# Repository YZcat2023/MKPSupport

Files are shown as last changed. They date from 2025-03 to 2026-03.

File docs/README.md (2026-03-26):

<div align="center" style="margin: 30px 0 30px 0">
   <a href="https://github.com/YZcat2023/MKPSupport">
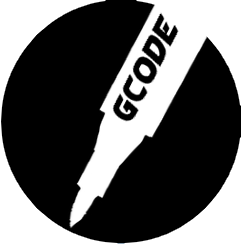
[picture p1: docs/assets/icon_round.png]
icon
      
   </a>
   <h3>MKP Support</h3>

   <p>
      
      
      
      
      
   </p>
   <p>
      </a>
   </p>
</div>

## ✨ What is MKP Support?

Still troubled by hard-to-remove 3D printing supports and the marks they leave behind? MKP Support makes removing supports as easy as peeling off a sticky note!

**In simple terms**: We've invented a method of applying an adhesive layer on the support interface, which leaves the contact surface smooth and flat, almost invisible, and incredibly easy to remove.

## 🖊️ Why is it better than traditional methods?

**Compared to standard supports**: No more prying with knives or pulling with pliers. Say goodbye to scratched fingers, while achieving an exceptionally smooth finish.

**Compared to water-soluble supports**: No need to buy specialized water-soluble filaments, no worries about moisture absorption. The results are nearly identical, but the cost is completely different.

**Extremely simple assembly**: The parts only require magnets, screws, springs (for P1/X1), pen refills, etc.

## 🎯 Expected Results

✅ **Saves Time**: Support removal goes from minutes to seconds.

✅ **Saves Material**: MKP doesn't require material changes or flushing.

✅ **Perfect Surface**: The support surface is flat and smooth.

✅ **Increases Success Rate**: Reduces the risk of damage during support removal.

## 📸 Demo

Showcase of actual printed test pieces. Note the extremely smooth support surface:

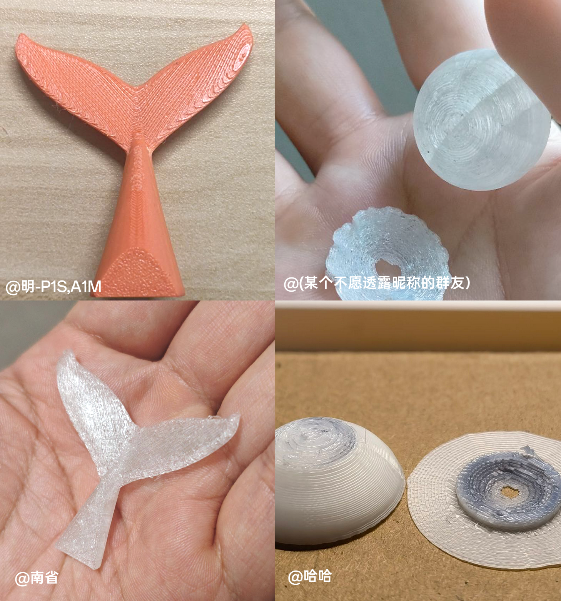
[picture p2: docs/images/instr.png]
sample


## 📦 Quick Start

### 1. Prepare Materials

🛒 You need to purchase the components indicated in the BOM list for your specific printer model.

  <a href="Printers/P1/"><strong>P1</strong></a><br>
  <a href="Printers/A1/"><strong>A1</strong></a><br>
  <a href="Printers/A1M/"><strong>A1M</strong></a>
### 2. Install Hardware

- **Download and Print** the parts for your printer model.
- **Assemble the parts**: Follow the instructional video to assemble the device.

### 3. Configure Software

**Download the program**: [Go to the Releases page](https://github.com/YZcat2023/MKPSupport/releases)

## 🛠️ In Development

🔧 **Planned for the near future**:

- [x] Multi-color printing support
- [x] More fine-tuning options
- [ ] Support for more printer models

📋 **See the full list**: [Issues page](https://github.com/YZcat2023/MKPSupport/issues)

For a complete list of proposed features (and known issues), please refer to the [issues](https://github.com/YZcat2023/MKPSupport/issues).

## 🤝 Contributing to This Project

- We are looking for capable developers to join us and make this project better. If you are willing to join, please feel free to contact us. We welcome you warmly.
- You can also help the developers by submitting [Pull Requests](https://github.com/YZcat2023/MKPSupport/pulls)! Submitting a pull request is also a way to contribute to this project. We will review your submission and then take over maintenance.
- Also, please see the [issues](https://github.com/YZcat2023/MKPSupport/issues).

### 🙏 Contributors

- Thanks to thyfk for programming supports and okookey for translating the English instructions

<!-- TODO: Contributor List -->

## 📄 License

This project is licensed under **The Unlicense**. This means you are free to use, modify, and distribute the code in this project. For more information, please refer to [`LICENSE`](../LICENSE).

## 📞 Contact Us

Please send an email to `Jhmodel01@outlook.com` or join the QQ group: 668350689.

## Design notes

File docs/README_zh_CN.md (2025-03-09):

<div align="center" style="margin: 30px 0 30px 0">
   <a href="https://github.com/YZcat2023/MKPSupport">
      icon
   </a>
   <h3>MKP Support</h3>
   <p>更好的 FDM 打印打印支撑方案</p>
   <a href="README.md">English</a> |
   <a href="#"><b>中文(简体)</b></a>
   <p>
      
      
      
      
   </p>
   <p>
      <a href="MKP%20Manual.pdf">
         <strong>Download MKP Manual »</strong>
      </a>
   </p>
</div>

## 关于本项目的一些想法

使用 [FDM 3D打印机](https://en.wikipedia.org/wiki/Fused_filament_fabrication#Fused_deposition_modeling) 打印零件时，
支撑总是一个让人头疼的问题。它们有时很难拆除，拆除支撑后的零件表面也不太平整。那么，降低支撑层与零件间的层粘也许是一个好主意？
试试看 [MKP Support](https://github.com/YZcat2023/MKPSupport) 吧，它能实现相当好的效果：

支撑面光滑平整不粘手，且颜色与零件主体没有区别。由于加入了熨烫支撑面的功能，也许效果比使用水溶支撑还要好。只需要四块磁铁，两个螺丝，一瓶液体胶等等，您就可以升级您的打印机。

我找来了一只马克笔涂抹支撑面，结果相当成功。接触面看上去很平滑。
不过，马克笔的方案并不十分令人满意：它似乎不能在 [CoreXY](https://en.wikipedia.org/wiki/CoreXY) 机器上工作。
于是我找来了一些*gluepen refills*(**点点胶替芯** in Chinese）。
胶水是透明的，因此接触面效果更加好了。不过，它似乎很容易就用完了。所以我设计了一个零件用来储存胶水，并且重新编写了程序。

### 想要达到的效果

- 减少时间与材料的浪费
- 提高接触面的表面效果
- 提高打印的成功率

## 演示

- 这是一些测试打印件, 可以从图片中看到支撑面打印效果

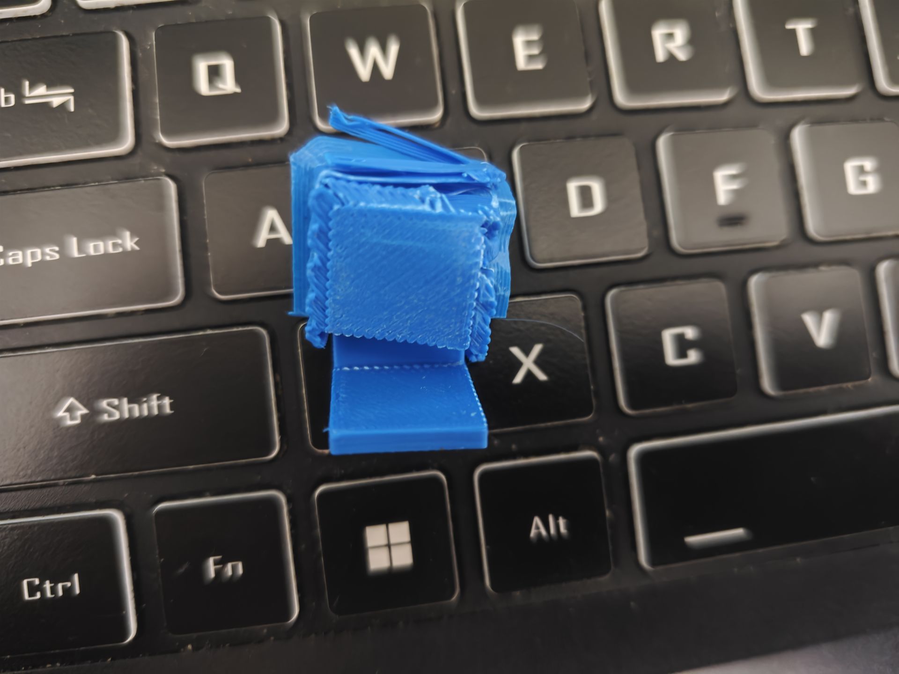
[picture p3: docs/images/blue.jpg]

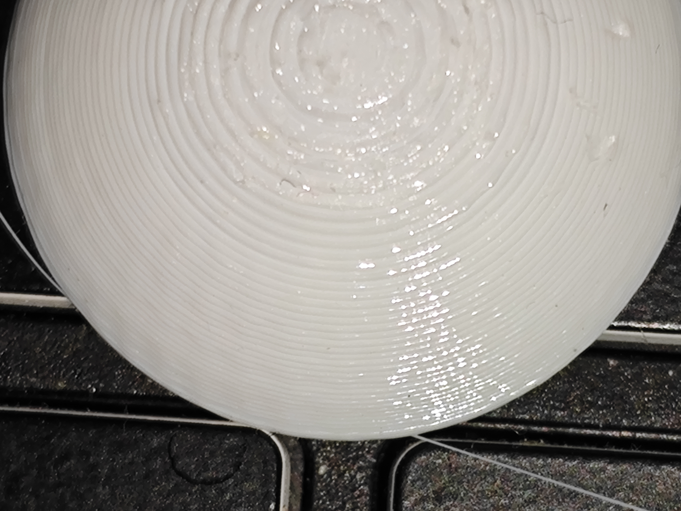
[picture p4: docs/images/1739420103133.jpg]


## 准备工作

想要获取更多信息，请参阅 [MKP Manual.pdf](MKP%20Manual.pdf)

1. 准备材料:
   * 点点胶笔芯、透明液体状办公胶水
   * M2.5*5 螺丝 **x 2**
   * 直径4毫米，厚度1.5毫米的磁铁 **x 4**
2. 模型的打印与装配:
   * 下载我们准备好的3D模型并完成打印。
   * 将打印件组装后安装在3D打印机的合适位置。
   * 根据实际机型可能需要调整模型完成适配。
3. 软件配置
   * 请到 [Releases](https://github.com/YZcat2023/MKPSupport/releases/latest) 页面下载对应的程序。
   * 将下载后的文件放在合适的位置，然后打开程序，在弹出的对话框内填写必要的参数生成配置文件。
   * 复制刚刚下载的程序路径到 Orca Slicer 的后处理脚本中。
     ```gcode
     ; 例如
     "C:/User/name/mkp/mkp.exe"
     ```
   * 调整切片设置确保能够完成 `gcode` 的插入

## 计划列表 & 已知问题

- [ ] 多色打印支持
- [x] 熨烫支持选项

有关提议功能（和已知问题）的完整列表，请参阅 [issues](https://github.com/YZcat2023/MKPSupport/issues)

## 为此项目做出贡献

- 我们正在寻找有能力的开发人员加入我们，让此项目变的更好，如果您愿意加入我们，欢迎联系我们，我们非常欢迎。
- 您也可以帮助开发者提交  [PullRequests](https://github.com/YZcat2023/MKPSupport/pulls)！
  提交请求也是一种对此项目的贡献方式，我们会审阅您的提交，然后接管维护下去。
- 另请参阅 [issues](https://github.com/YZcat2023/MKPSupport/issues)

### 贡献名单

- Thanks to thyfk for programming supports and okookey for translating the English instructions

<!-- TODO: 贡献者成员名单 -->

## License

此项目采用 **The Unlicense** 许可授权。这意味着您可以自由使用、修改、分发本项目中的代码，有关信息请参阅 [`LICENSE`](../LICENSE)

## 联系我们

请发送邮件到 `Jhmodel01@outlook.com`

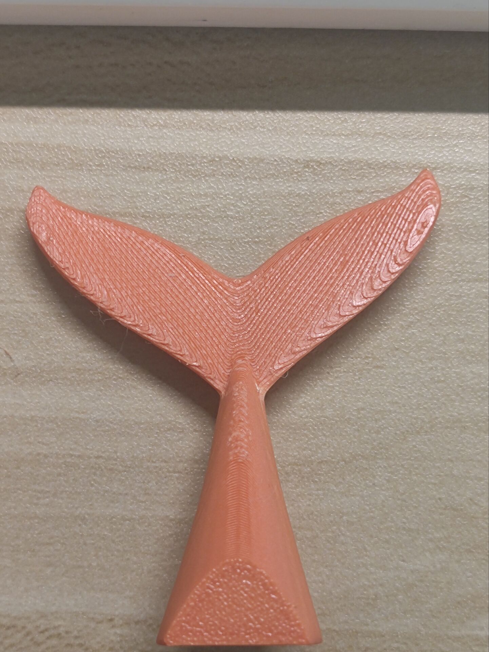
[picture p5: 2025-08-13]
docs/images/whale.jpg

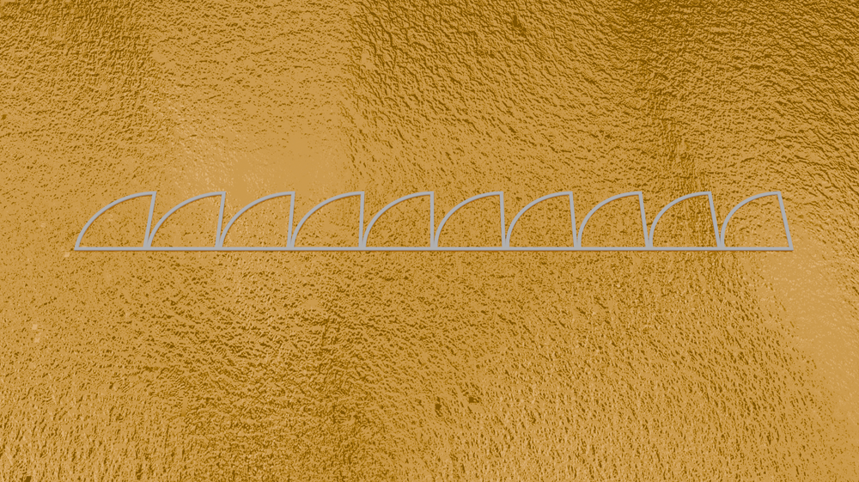
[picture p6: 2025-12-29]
resources/lshape.png

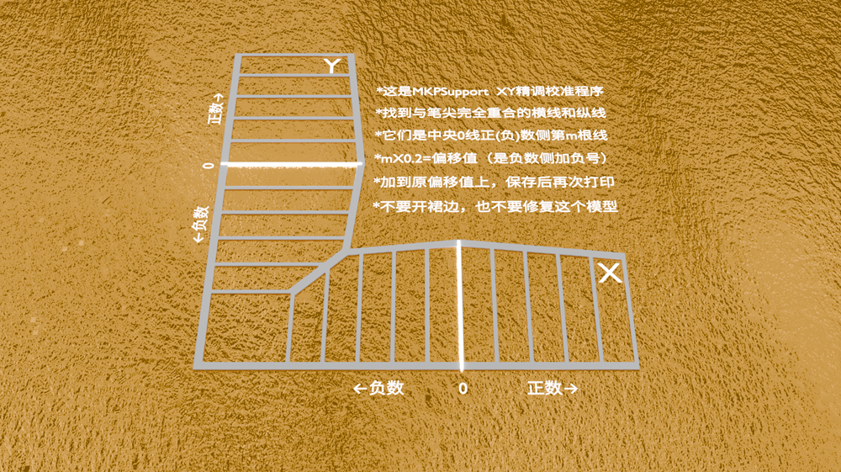
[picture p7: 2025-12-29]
resources/xy_calibr.png

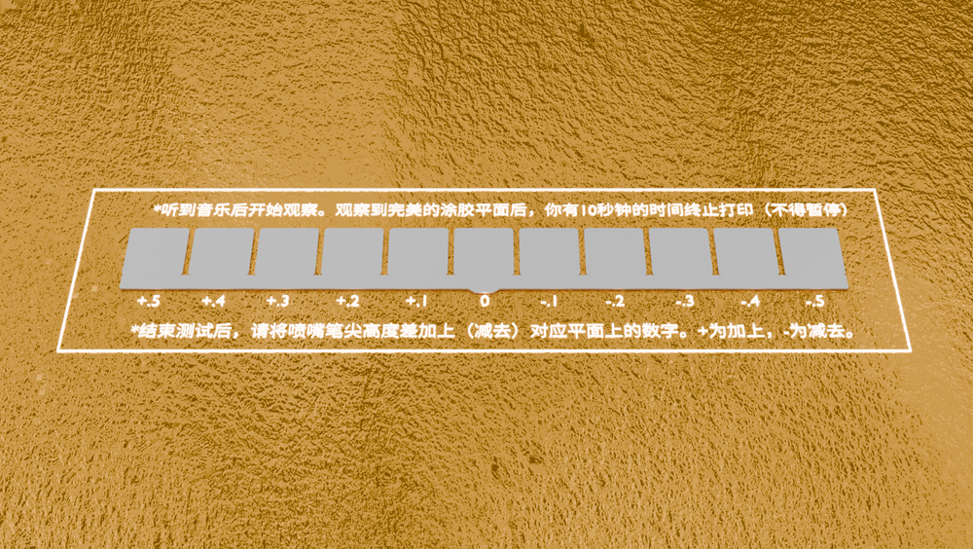
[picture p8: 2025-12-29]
resources/z_calibr.png

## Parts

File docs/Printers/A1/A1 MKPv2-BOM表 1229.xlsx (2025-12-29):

项目 | 所需数量 | 用途 | 淘宝链接 | 备注
大容量高温消失笔芯 | 若干，买替芯就够了 | 笔芯 | 【淘宝】7天无理由退货 https://e.tb.cn/h.7TaKxUg8qL7QzkJ?tk=IIopfzxPCTx HU006 「巨无霸高温消失笔芯大容量服装厂记号笔划线熨烫加热自动褪色无痕」 点击链接直接打开 或者 淘宝搜索直接打开 | 点点胶替芯不再作为推荐
4mm直径2mm厚度N35磁铁 | 至少5 个，以防万一可以多买几个 | 磁吸 | 【淘宝】https://e.tb.cn/h.SyAmDUdPumDhL0F?tk=vin3fLGG5OZ CZ193 「磁铁强力高强小磁钢吸铁石迷你片贴片圆形长方形钕永磁铁方块打捞」 点击链接直接打开 或者 淘宝搜索直接打开 | N52太强了，可能不合适
M2.5*5平头螺丝 | 至少 9 枚 | 组装 | 【淘宝】大促价保 https://e.tb.cn/h.TK1PfH7ZzDrkUwZ?tk=xzIGe6OmARt HU591 「304不锈钢CM超薄头大平头极低扁平C头内六角螺丝钉M2.5M3M4M5M6M8」

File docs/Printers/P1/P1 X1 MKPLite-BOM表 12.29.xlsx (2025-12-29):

项目 | 所需数量 | 用途 | 淘宝链接 | 备注
大容量高温消失笔芯 | 若干，买替芯就够了 | 笔芯 | 【淘宝】7天无理由退货 https://e.tb.cn/h.7TaKxUg8qL7QzkJ?tk=IIopfzxPCTx HU006 「巨无霸高温消失笔芯大容量服装厂记号笔划线熨烫加热自动褪色无痕」 点击链接直接打开 或者 淘宝搜索直接打开 | 点点胶替芯不再作为推荐
4mm直径2mm厚度N52磁铁 | 至少5 个 | 磁吸，嵌入打印的外壳 | 【淘宝】退货运费险 https://e.tb.cn/h.hyI3OSTP9Ipsg0g?tk=OOv04L8GONQ CZ193 「N52强磁小圆形2-8mm迷你强力吸铁石高性能钕铁硼小磁铁超强吸磁钢」 点击链接直接打开 或者 淘宝搜索直接打开
M2*5平头螺丝 | 若干 | 组装 | 【淘宝】大促价保 https://e.tb.cn/h.TK1PfH7ZzDrkUwZ?tk=xzIGe6OmARt HU591 「304不锈钢CM超薄头大平头极低扁平C头内六角螺丝钉M2.5M3M4M5M6M8」
弹簧（0.4*4.5*18mm) | 一根(自用的话不需买） | 回弹 | https://mobile.yangkeduo.com/goods2.html?ps=6SXQYdtmWP | 可从其他圆珠笔拆出

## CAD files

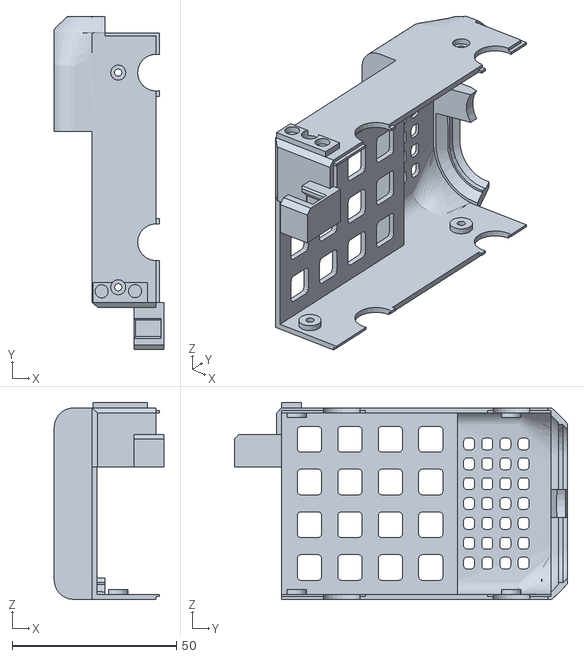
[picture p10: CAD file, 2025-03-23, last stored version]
Printer Parts/Bambu/Bambu P1,X1/后盖.stl
33.4 x 101.4 x 59.9

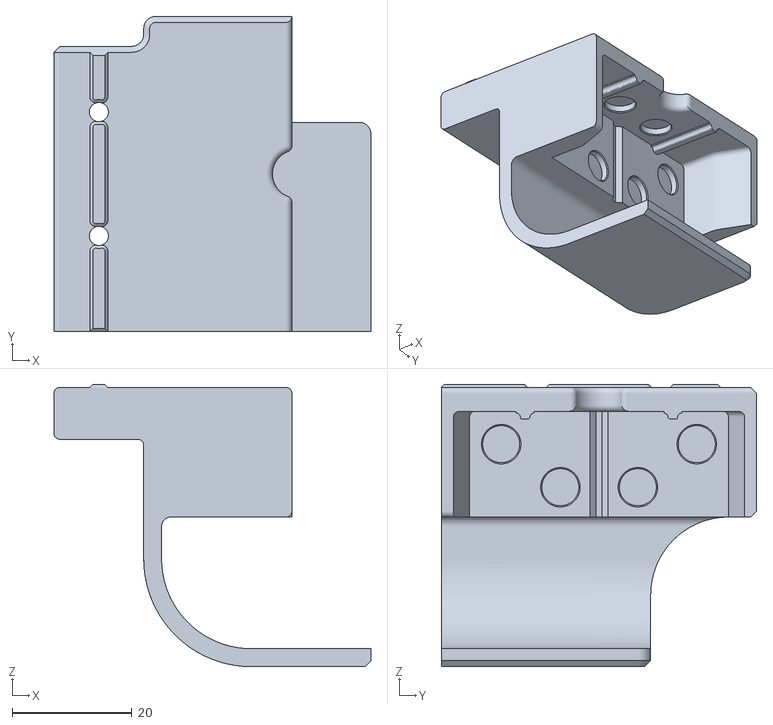
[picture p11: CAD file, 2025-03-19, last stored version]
Printer Parts/Voron/Voron2.4/胶箱停靠站.stl
53.0 x 52.7 x 47.2

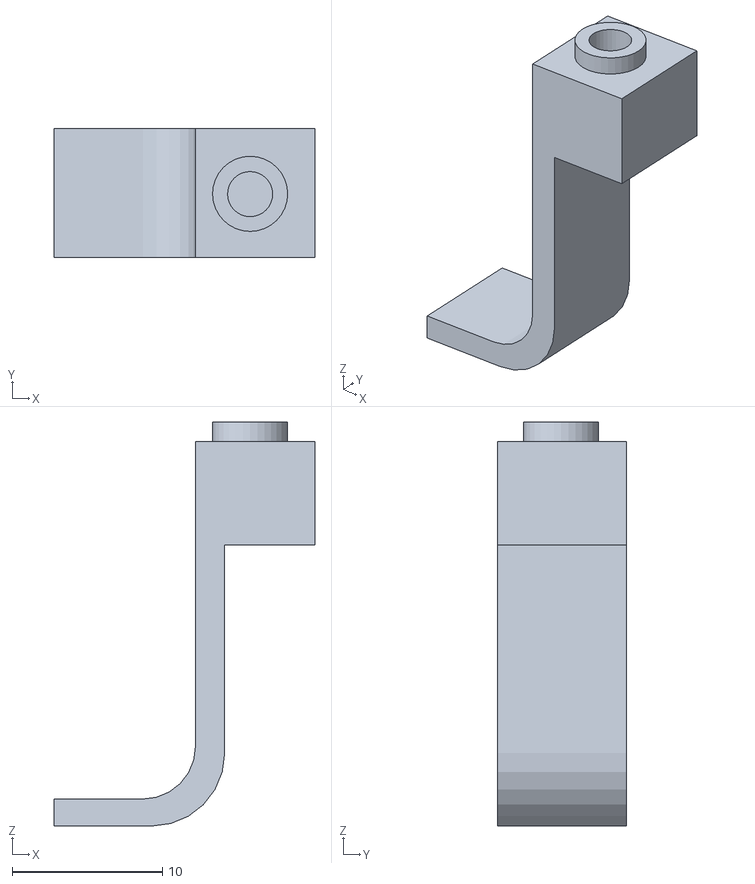
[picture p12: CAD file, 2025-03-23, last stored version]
Printer Parts/Bambu/Bambu P1,X1/笔垫.stl
17.3 x 8.55 x 26.9

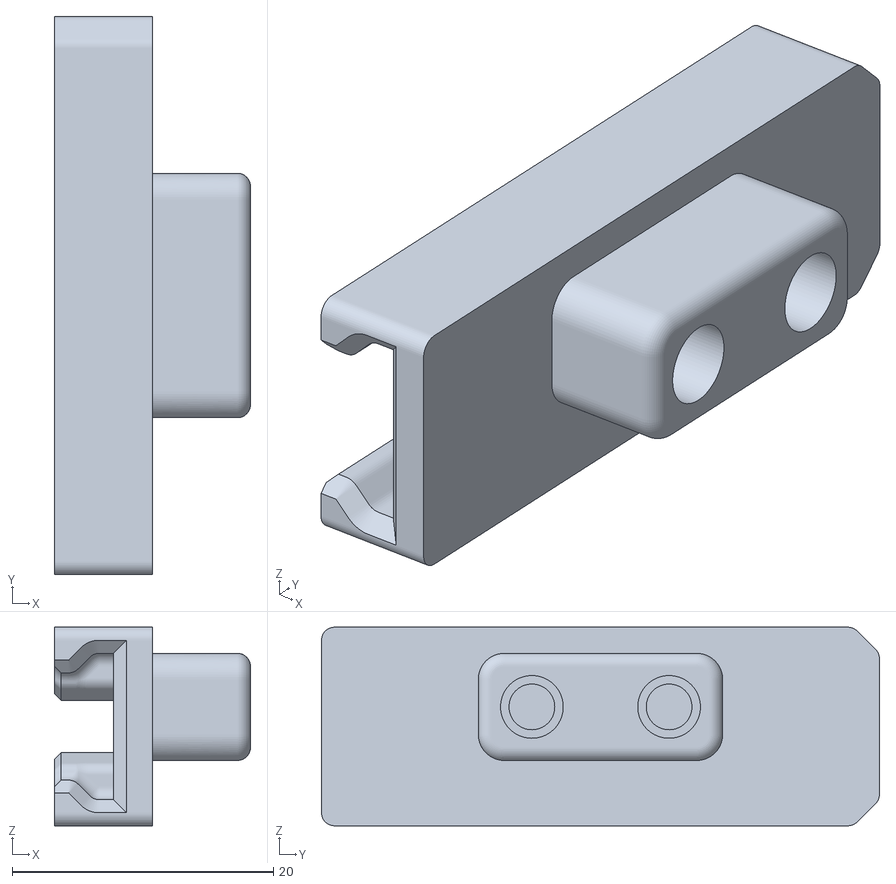
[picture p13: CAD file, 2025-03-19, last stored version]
Printer Parts/Voron/Voron2.4/打印头滑槽.stl
15.0 x 42.7 x 15.2

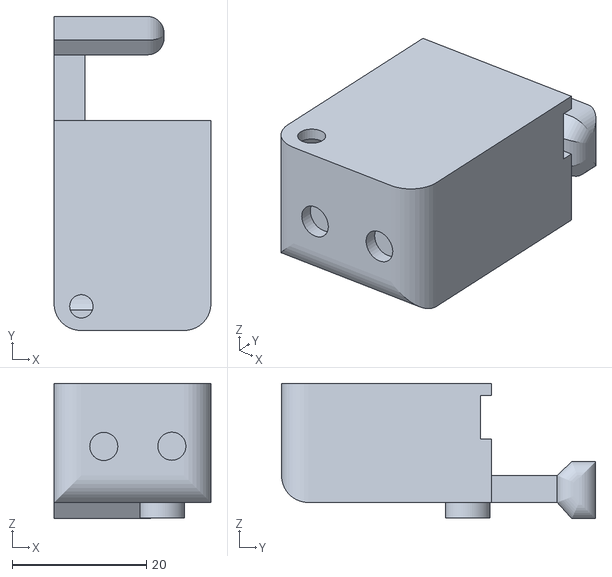
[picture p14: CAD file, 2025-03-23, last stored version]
Printer Parts/Bambu/Bambu P1,X1/胶箱.stl
23.4 x 46.9 x 20.2

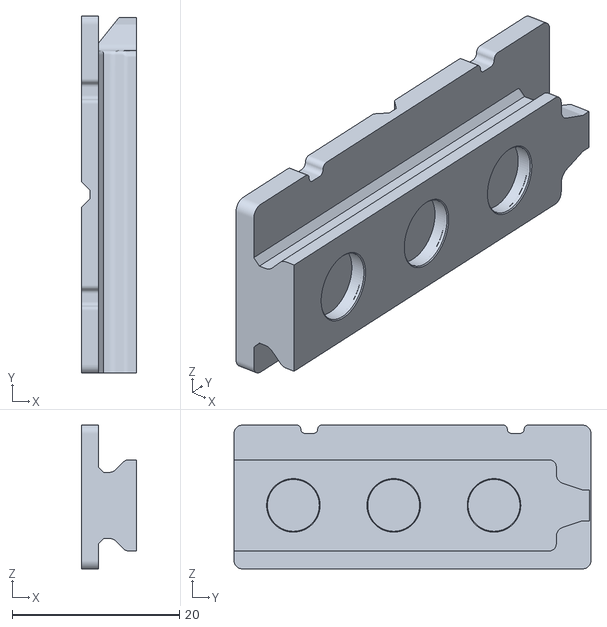
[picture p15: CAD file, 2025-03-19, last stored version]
Printer Parts/Voron/Voron2.4/胶箱滑槽.stl
6.55 x 42.7 x 17.2

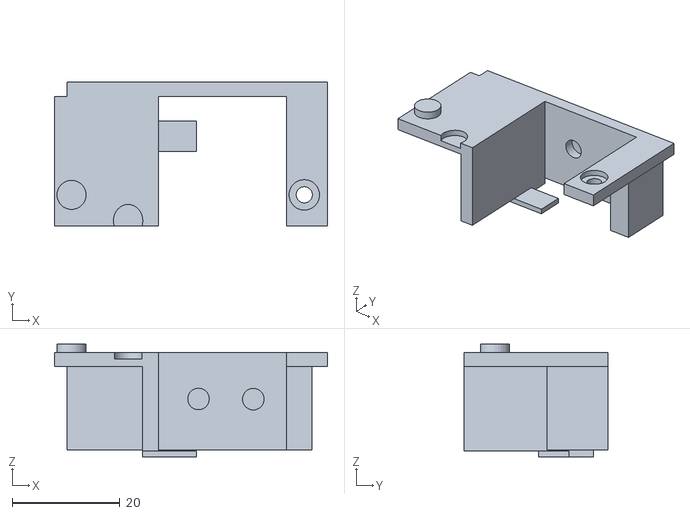
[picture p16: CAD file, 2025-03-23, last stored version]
Printer Parts/Bambu/Bambu P1,X1/坞.stl
50.6 x 26.8 x 20.9

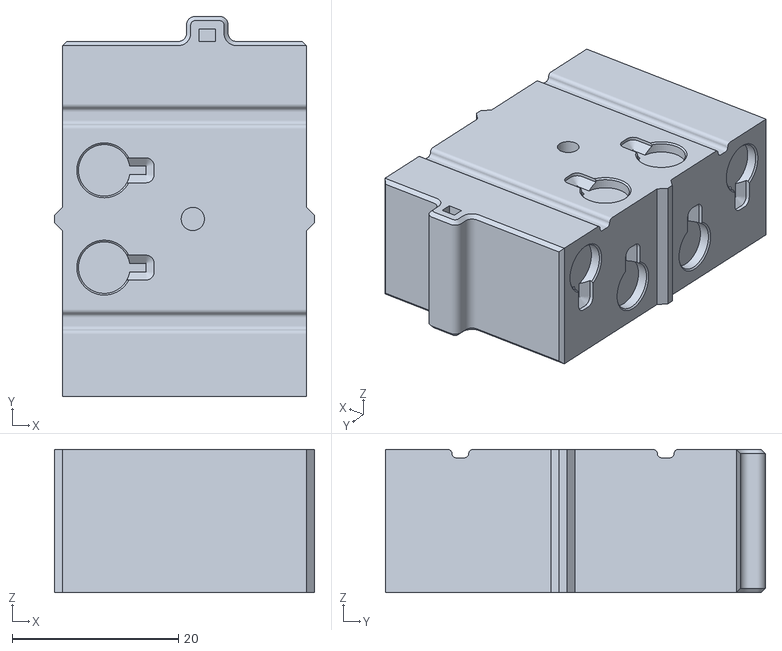
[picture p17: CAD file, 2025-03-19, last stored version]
Printer Parts/Voron/Voron2.4/胶箱.stl
31.3 x 45.7 x 17.2

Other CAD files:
Bambu P1,X1/p1.blend
Printer Parts/Bambu/Bambu P1,X1/p1.blend
Printers/Bambu/Bambu P1,X1/p1.blend

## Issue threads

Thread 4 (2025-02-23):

对于 Bambu P1S 的支持

Xing-C, 2025-02-23:

suqiernb, 2025-03-05:
正在进行适配 Bambu Lab X1/P1 系列

Xing-C, 2025-03-09:
非常期待。

YZcat2023, 2025-03-21:
我们绘制了测试版的组件了，现在正在准备测试

Xing-C, 2025-03-21:
> 我们绘制了测试版的组件了，现在正在准备测试

真的是太好了，多么好的消息，也期待！

YZcat2023, 2025-04-03:
现在我们可以流畅的挂载和卸载胶箱了，不过由于BBS的更新，我们需要修改程序以适应新的特性

Xing-C, 2025-04-03:
> 现在我们可以流畅的挂载和卸载胶箱了，不过由于BBS的更新，我们需要修改程序以适应新的特性

给我个联系方式，也许我能帮点忙。。

YZcat2023, 2025-04-04:
QQ,MKPSupport交流群668350689

Xing-C, 2025-04-04:
> QQ,MKPSupport交流群668350689

来了。

YZcat2023, 2025-08-13:
completed.

Closed 2025-08-13.

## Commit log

2025-02-17 chore(project): reorganize project structure
    [BOM表.xlsx]
2025-03-12 Move user manual from /docs to /Manual
    Relocated the user manual documentation to a more appropriate directory
    structure for better organization.
    [BOM表.xlsx]
2025-03-19 voron2.4模型适配
    [打印头滑槽.stl, 胶箱.stl, 胶箱停靠站.stl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]
2025-03-23 Experimental parts for Bambu X1 and P1
    [p1.blend, 后盖.stl, 坞.stl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]
2025-03-23 Rename to suit the routines
    [p1.blend, 后盖.stl, 坞.stl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]
2025-03-23 Rename to make this clear
    [p1.blend, 后盖.stl, 坞.stl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]
2025-12-29 Update printer model links in README

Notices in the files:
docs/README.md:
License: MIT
